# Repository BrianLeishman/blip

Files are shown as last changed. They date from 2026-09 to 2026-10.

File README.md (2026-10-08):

# blip

**Brian’s Little Information Panel.** A little physical home for your GitHub queue:
TinyGo, a color screen, a clickable knob, and a 3D-printed case.

Turn the knob to select something. Click to open it in your computer’s default
browser. Swipe the screen to scroll. One dashboard, no pages or menus.

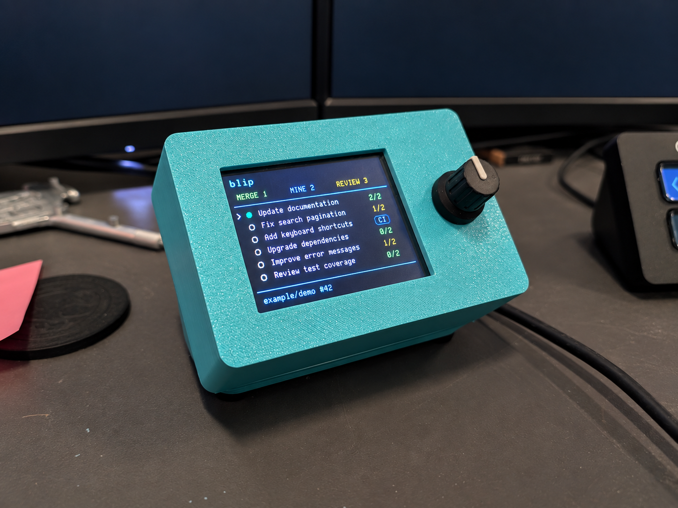
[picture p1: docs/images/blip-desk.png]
A working blip in its teal printed enclosure


*AI privacy edit of the working desk prototype photo: LCD content is fictional
and background monitors are blanked. [Image provenance](docs/images/README.md).*

## What it does

- **Merge:** your PRs that meet the dashboard’s review rules, with failing checks and
  merge conflicts keeping them out of the ready queue. Pending CI is shown with
  a spinner and can still appear here.
- **Mine:** your other PRs, with approval counts, LGTM labels, and CI status.
- **Review:** open, non-draft PRs requesting your review, oldest updated first,
  while they still have fewer than the configured number of approvals. PRs with
  running or failing CI, or merge conflicts, stay hidden until resolved.
- **Urgent:** optional GitHub issue Priority filtering, excluding blocked work.
- **Across repositories:** discover relevant PRs across configured organizations
  and personal accounts; skip archived repositories.
- **Extra authors:** optionally treat Dependabot and configured GitHub accounts
  as yours, hiding their PRs assigned exclusively to somebody else.
- **Comments:** unread human comments on subscribed issues and PRs. Click to open
  the specific comment and clear the alert locally; new comments bring it back.
  Drafts are excluded, queued items appear once, and standalone PR alerts cover
  conversations you've participated in or direct mentions.
- **Deployments:** unresolved failures from configured production workflows.
  A newer successful or cancelled run clears the alert. PR CI failures remain
  in the existing PR status display.

Running checks get a spinner. Long selected titles marquee. Turn past either end
of the list to clear the selection and stop the scrolling title. The footer shows
the item number, repository, and status. Content updates only repaint when the
content changes; animations replace only the affected row as a composed bitmap.

Clicking opens a GitHub page—even when the displayed data is stale. **Blip never
merges a PR, submits a review, or changes an issue.** The Merge section is a personal
queue; GitHub remains authoritative about mergeability and branch protection.

## How it works

```text
GitHub ← authenticated gh CLI ← Go companion on your computer
                                      ↕ USB serial
                              Feather RP2040 + TinyGo
                                ↙              ↘
                           TFT screen       rotary knob
```

The companion fetches GitHub data and opens links. The Feather handles display,
selection, touch scrolling, and button presses. Credentials stay on the computer;
the device receives display data and repository/item IDs, never access tokens.
There is no hosted backend or Wi-Fi setup.

macOS is the tested host. Linux has serial support and an `xdg-open` path, but has
not been hardware-tested. The screen is a **2.4-inch, 320 × 240 color TFT** with
resistive touch.

## Hardware

| Qty | Part |
| --- | --- |
| 1 | [Adafruit Feather RP2040 — #4884](https://www.adafruit.com/product/4884) |
| 1 | [2.4-inch TFT FeatherWing V2 — #3315](https://www.adafruit.com/product/3315) |
| 1 | [STEMMA QT rotary encoder breakout — #4991](https://www.adafruit.com/product/4991) |
| 1 | [Rotary Encoder + Extras — #377](https://www.adafruit.com/product/377), including knob |
| 1 | [100 mm STEMMA QT cable — #4210](https://www.adafruit.com/product/4210) |
| 1 | USB-C **data** cable |
| 1 | Short flexible USB-C extension for routing through the case |
| — | M2.5 board screws, M3 case screws, rubber feet, hookup wire and printed parts |

You will also need soldering tools and a printer or printing service. No battery,
SD card, or breadboard is required. See the [assembly guide](enclosure/v2/ASSEMBLY.md)
for screw lengths, wiring, and the current fit limitations before buying or printing.

For a first bench test, the Feather can plug directly into the FeatherWing’s two
header sockets; match the pin labels. Solder the rotary encoder into its breakout
and connect the breakout’s QT cable to the **Feather’s QT port**.

The compact case relocates the Feather using eight wires: **3.3V, GND, SCK, MOSI,
D9, D10, SDA, SCL**. Important: use the FeatherWing’s **3.3V socket, second from
RST**; the next socket is AREF. The [wiring guide](enclosure/v2/ASSEMBLY.md#eight-wire-connection)
explains the orientation and optional connections.

## Get it running

Requires Go matching [go.mod](go.mod) (currently 1.26.6+), TinyGo 0.42+, and the
GitHub CLI. Python 3 is only needed for the optional macOS service installer and
CAD utilities; OpenSCAD is needed to regenerate the printed parts.

```sh
git clone https://github.com/BrianLeishman/blip.git
cd blip
gh auth login
make all
```

For the first flash, hold **BOOTSEL**, tap **RESET**, then release BOOTSEL. Copy
`build/blip.uf2` to the `RPI-RP2` drive. Before the companion connects, the hardware
test screen shows knob position and click counters.

```sh
cp blip.example.json blip.local.json
# Edit blip.local.json: replace the example owners with yours.
make run
```

The companion detects the connected Adafruit serial device and reconnects after
unplugging it. Use `./build/blip -port /dev/cu.usbmodem…` if detection is ambiguous.
`make probe` prints hardware events; `./build/blip -once` prints a GitHub snapshot
without connecting to the device. The latter can include private repository data.

To keep the companion running at login on macOS:

```sh
python3 scripts/macos-service.py
# To remove it later:
python3 scripts/macos-service.py --uninstall
```

Before probing or flashing, stop the service so only one process owns the port:

```sh
launchctl bootout gui/$(id -u)/com.brianleishman.blip
make flash
python3 scripts/macos-service.py
```

See [configuration and dashboard behavior](docs/dashboard.md) for review rules,
urgent issue queries, polling limits, stale data, and troubleshooting.

## Printed enclosure

OpenSCAD source and printable STLs are included. The case is meant to be tinkered
with: a tilted screen, knob on the right, a hollow base, and a rear USB cable plate.

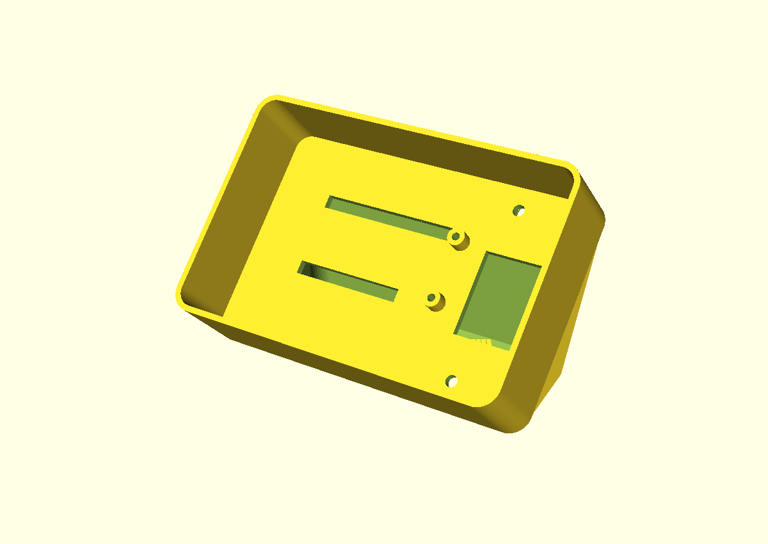
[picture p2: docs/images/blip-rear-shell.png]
Latest rear-shell CAD render, showing Feather mounts and header clearance slots


*CAD render of the latest revision. This is newer than the case in the photo and
has not yet been physically printed and verified.*

The photographed build works, but the rotary fit is tight and wiring space needs
improvement. The latest CAD moves the sidewalls onto the rear shell, outside the
fit-tested face area, and adds clearance slots for the Feather’s pins. It still
uses **two Feather posts**; four slightly taller posts are planned, not implemented.

- [Assembly and print instructions](enclosure/v2/ASSEMBLY.md)
- [Parametric OpenSCAD source](enclosure/v2/assembly.scad)
- [Front plate STL](enclosure/stl/v2-front-m25.stl)
- [Rear shell/base STL](enclosure/stl/v2-stand.stl)
- [USB plate STL](enclosure/stl/v2-usb-plate.stl)
- [All three parts, arranged for printing](enclosure/stl/v2-print-layout.stl)

```sh
make enclosure-v2
```

The combined STL is a layout of **three separate parts**, not an assembled solid.
Mesh and modeled-clearance checks help catch CAD mistakes, but do not validate
real wire bends, printer tolerances, or physical fit. Earlier enclosure experiments
remain in [enclosure/](enclosure/README.md).

## Development and privacy

```sh
make test       # Go tests and vet
make firmware   # TinyGo build, without flashing
```

`firmware/` drives the hardware, `dashboard/` shares the wire model and list behavior,
and `cmd/blip/` plus `internal/github/` implement the companion.

Personal configuration, build output, logs, and environment files are ignored.
Do not commit live snapshots or unredacted photos: titles, repository names, and
computer screens can reveal private work even without a token. See
[security and privacy notes](SECURITY.md) before sharing diagnostics.

## License

MIT. Dependencies keep their own licenses. Adafruit’s hardware designs are
separately licensed and linked as dimensional references; their PCB files are not
vendored here.

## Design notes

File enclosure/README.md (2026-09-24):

# OpenSCAD enclosure

`blip.scad` is the editable source. `stl/front.stl` and `stl/back.stl` are generated
from it. The default view is an exploded assembly. Select `part="fit"` to export
a shallow bezel/mounting test before printing the complete case. The fit test
uses 1.7 mm board pilot holes for M2 screws and 2.6 mm case pilot holes for
M3 screws to form threads directly in printed plastic. No inserts or captive nuts are needed. Test screw fit gently
before mounting the electronics; adjust `board_screw_pilot` or `case_screw_pilot` if your print is too tight
or too loose, especially with nylon screws. Do not force a screw that binds.

**Prototype: not physically fit-tested.** PCB outline and mounting-hole centers
come from Adafruit's V2 Eagle file. Screen stack height, viewing-window alignment,
encoder bushing fit, cable opening, and screw fit still need checking
against the assembled hardware. Do not treat these exports as a proven fit.

## Geometry and hardware

- 115 x 76 x 32 mm case; 2.4 mm walls and a 2 mm face.
- Screen PCB: 64.770 x 52.578 mm in landscape, holes inset 2.540 mm.
- Screen mounting pattern is mirrored horizontally about the unchanged window
  center, swapping the close and far pairs. This moves the PCB origin from
  x=8 to x=11.63 mm while retaining the mounting-hole spacing.
- Four screen posts with M2 pilot holes. LCD-facing sides are trimmed to
  2.0 mm from each screw center; the outer sides retain the original radius.
- Four case posts with M3 pilot holes; rear lid has 3.3 mm clearance holes.
- Encoder mounts through the face with its included washer/nut. Two 3 mm
  tall rails locate its metal body against rotation. Their 13.8 mm spacing
  includes 0.3 mm clearance per side around the nominal 13.2 mm body.
  Rails are rotated 45 degrees to match the encoder-to-breakout orientation;
  verify fit before tightening. Adjust `encoder_gap`/`encoder_angle` if needed.
- Broad top-edge USB service opening leaves clearance for the cable; refine after fitting.
- Flat rear lid with vents; rubber feet attach to its outside.

The revised screen posts are 2.54 mm shorter, leaving 2.96 mm of blind-hole
depth. Use M2 x 4 mm screws with a 1.6 mm PCB (2.4 mm engagement), or check
your actual stack so screw protrusion stays below 2.96 mm. The earlier
6 mm screen screws are too long without suitable spacers.
The rear lid is 2.4 mm thick; a 6 mm screw leaves 3.6 mm engagement in the shell.
Do not tighten against the LCD glass.
The knob must retain enough axial clearance to click without rubbing the face.
The current shell is flat; an angled desk stand can be added after hardware fit.

Print front face-down (the SCAD export already places that face on Z=0), and back
flat. Suggested starting settings: 0.2 mm layers and three perimeters. The USB
opening involves a bridge; use supports locally if required
by your printer/material. Printer and filament are user-supplied.

```sh
make enclosure
openscad -o build/fit.stl -D 'part="fit"' enclosure/blip.scad
```

Physical fit feedback: with the screen readable, USB exits below it. The
current full shell's top service opening is therefore not validated and must
be rerouted before a full-case print. The shallow fit test does not depend on
USB opening position.

Use `stl/bezel-fit-mirrored-short.stl` for the revised combined fit test.
Previous fit exports are superseded. For a smaller encoder-only trial, export
`part="encoder-fit"`; it checks body indexing and knob click clearance.

Dimensional sources:
- https://github.com/adafruit/Adafruit-2.4-TFT-FeatherWing-PCB
  (`Adafruit 2.4in TFT FeatherWing V2.brd`)
- https://learn.adafruit.com/adafruit-2-4-tft-touch-screen-featherwing/downloads
- https://www.adafruit.com/product/377

The vendor CAD was read for dimensions and is not included in this repository.

Encoder dimensions: [Adafruit encoder PCB](https://github.com/adafruit/Adafruit-I2C-QT-Rotary-Encoder-PCB),
`PEC11+SWITCH` package (13.2 mm body outline, center-mounted at MR135).

## Compact enclosure with 45-degree stand

`slim.scad` is the current enclosure. `blip.scad` retains the larger fitting
reference. The face is 104 x 61 mm, with the corrected screen offset and
4.96 mm PCB mounting height. Shell plus rear cover depth is 32 mm. The stand
holds the face at 45 degrees; assembled desk footprint is approximately
104 x 68 mm, about 70 mm high, excluding rubber feet.

Build all current parts with `make enclosure-slim`:

- `stl/slim-front-m25.stl`: front shell, relieved screen posts, encoder rails.
- `stl/slim-stand.stl`: hollow stand and rear cover, printed as one part.
- `stl/slim-usb-plate.stl`: replaceable rear cable plate.
- `stl/slim-face-fit-m25.stl`: optional shallow fit print using the same mounts.

Hardware:

- Four M2.5 x 4 mm pan/button-head screws for the screen PCB. Vendor CAD
  specifies 2.5 mm drilled mounting holes; check free passage on the actual
  plated board. Printed pilot holes are 2.2 mm. The nominal 1.6 mm PCB leaves
  2.4 mm screw engagement in 2.96 mm-deep blind holes. Do not use 8 mm screws.
- Four M3 x 8 mm screws fasten the stand/rear cover to the shell (2.4 mm cover,
  5.6 mm engagement). Four 7.5 mm access bores in the stand admit the heads
  and a slim driver. Two are reached from the back, two from underneath.
- Two M3 x 6 mm screws fasten the rear cable plate. A small zip tie secures
  the extension body using the adjacent slots; do not clamp bare ribbon wire.
- Encoder's supplied nut and washer, plus the existing rubber feet.
- No inserts or captive nuts required.

Assembly: fit the screen using the short screws, install the encoder between
its indexing rails and secure its nut, connect QT and USB, route the USB
extension through the 24 x 12 mm rear-cover transfer opening into the hollow
stand, and attach the stand using the four M3 screws. The cover has an inset
locating skirt. Secure the extension at the rear plate, attach the plate,
and place rubber feet on the four solid underside corner areas. The large
underside opening provides access to wiring and the lower cover screws.

USB routing is designed for a short flexible **data-capable** USB-C male-to-
female extension, preferably with a low-profile right-angle male connector.
The current rear plate has a generic 18 x 10 mm pass-through and tie slots;
it is not a precision panel mount for an identified cable. Adjust `usb_slot_w`
and `usb_slot_h`, or replace just this plate, once the extension is selected.
The lower shell service opening accommodates the plug; exact connector/body
clearance and cable bend radius remain physical-fit checks. The QT board gap
is nominally 4.13 mm, so check the QT connector/cable clearance too.

Print the front face down, the stand base down, and the cable plate flat,
as exported. Start with 0.2 mm layers and 3-4 perimeters. Inspect the slicer:
local supports may be useful under the shell USB opening and the stand's
rear cable opening; avoid filling the entire hollow stand with supports.
The sloped roof starts on a supporting front lip. All parts remain prototypes
until physically assembled; rendering alone does not validate hardware fit.

## Tapered cable-pocket revision (September 23)

`tapered.scad` is a separate fit prototype; `slim.scad` remains unchanged.
The user confirmed USB currently exits the top with the knob on the right.
This revision rotates the PCB mount pattern 180 degrees about the unchanged
screen opening so USB exits below the display. The front shell has been physically installed and the user reports it clears,
with little spare room. Firmware now uses Rotation270 with the matching
touchscreen mapping for this orientation. Base fit is still pending.

The front stays 104 x 61 mm with the same screen opening and knob placement.
Behind it, the case flares to 116 x 76.24 mm: 6 mm per side and an additional
15.24 mm (0.600 inch) below the original lower inner wall. Side relief reaches
full width at the 4.96 mm PCB plane; lower relief reaches full size 12 mm behind
the front face. These are provisional cable envelopes, not measured plug models.
The lower pocket routes through a 40 x 18.24 mm opening into the hollow stand.
The stand matches the enlarged rear cover and still holds the face at 45 degrees.
The underside is raised to keep the enlarged shell above the desk.

Build with `make enclosure-tapered`:

- `stl/tapered-front-m25.stl`
- `stl/tapered-stand.stl`
- `stl/tapered-face-fit-m25.stl` (optional shallow mounting check)

Reuse `stl/slim-usb-plate.stl` and the M2.5 x 4 mm / M3 hardware described above.
The left PCB bosses are clipped at the front edge after rotation; no inserts.
The rear connector plate remains a generic opening, pending actual female
connector measurements. Do not assume it is a precise clamp for the new cable.

Print front face-down with supports as needed under the outward flare (the
side flare is steep); stand base-down. Inspect support access in the slicer.
Verify USB connector depth, bend clearance, QT routing, and the rotated screen
alignment before a final print. The shallow coupon checks mounting, not cables.

## V2 packing study

The [V2 component study](v2/README.md) uses vendor PCB outlines and explicit
connector-clearance estimates to compare stacked and relocated Feather layouts.
Open `v2/packing.scad` to inspect; run `make enclosure-v2-check` for envelope and
collision reports. This is separate from the assembled V1 tapered enclosure.

## Compact V2 full assembly

See [V2 assembly instructions](v2/ASSEMBLY.md) for the 97.57 × 65 × 28 mm case,
upside-down relocated Feather and required low-profile wiring. Run
`make enclosure-v2`; `stl/v2-print-layout.stl` contains all three printable parts.

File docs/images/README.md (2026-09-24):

# README image provenance

`blip-desk.png` is an AI privacy edit of the author's photograph of the working
printed prototype. Background monitor content was removed and LCD content
replaced with fictional demo items. It is not an exact screenshot of the firmware.
The original work photograph is intentionally not included in the repository.
The edit used the built-in imagegen tool. PNG metadata was removed without
changing the rendered pixels.

`blip-rear-shell.png` is an OpenSCAD render of `enclosure/v2/assembly.scad` with
`part="stand"`, showing the newer rear-shell walls and header-clearance slots.
That revision has not been physically printed and verified.

## Photo edit prompt

Use case: precise-object-edit. Edit this real project photograph for a public GitHub README. Preserve the real teal 3D-printed enclosure, its shape, textured filament, black knob, desk, perspective, and lighting exactly. Privacy edits only: replace ALL content on ALL background computer monitors with plain dark blank screens, no text or windows. Replace ALL content on the small device LCD with a similar tiny pixel-font dashboard containing only fictional generic demo text: header 'blip', tabs 'MERGE 1  MINE 2  REVIEW 3'; rows 'Update documentation', 'Fix search pagination', 'Add keyboard shortcuts', 'Upgrade dependencies', 'Improve error messages', 'Review test coverage'; generic badges '2/2', '1/2', 'CI', '0/2'; footer 'example/demo #42'. Absolutely remove every original PR title, number, repository name, customer name and all original LCD footer content. Do not change hardware or invent new features. Keep realistic photographed LCD perspective and pixelated appearance. Crop excess empty desk for a landscape hero image while keeping the complete device and base. No added branding, annotations, watermarks, or other text.

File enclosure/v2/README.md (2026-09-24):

# V2 enclosure and component packing study

**Current full-case prototype:** [assembly and printing instructions](ASSEMBLY.md).
The notes below retain the earlier packing-study comparisons. The full case now
uses the successfully tested eight-wire relocation and an upside-down Feather.

`packing.scad` models the existing boards and provisional connector clearances to
compare layouts before designing another enclosure. **This is not a printable
case or a guarantee of physical fit.** V1 remains in `../tapered.scad`.

Open `packing.scad` in OpenSCAD. Set `layout` to `stacked`, `remote-flat`, or
`remote-edge`; `qt_source` chooses `feather` (default) or `screen`; `view` supports `assembly`, `exploded`, `collision`, and `envelope`.
Green is the screen PCB, blue the Feather, purple the encoder PCB, and amber the
reserved connector/cable space. Red indicates intersections included in the
collision check. Axes: x right, y down the display, z behind its face; the knob
projects into negative z. This is a component layout, not the tilted desktop stand.

## Published geometry

| Part | PCB outline from vendor CAD | Other published dimensions |
|---|---|---|
| [TFT FeatherWing V2 #3315](https://www.adafruit.com/product/3315) | 64.770 × 52.578 mm landscape | Product overall height 9.5 mm; LCD footprint outline 60.15 × 42.6 mm |
| [Feather RP2040 #4884](https://www.adafruit.com/product/4884) | 50.800 × 22.860 mm | Product overall height 7.5 mm, not assembled header-stack height |
| [Encoder breakout #4991](https://www.adafruit.com/product/4991) | 25.400 × 25.400 mm | Product height 4.6 mm without the separately soldered encoder |
| [Encoder + knob #377](https://www.adafruit.com/product/377) | Encoder body footprint 13.2 × 13.2 mm | Supplied knob base diameter 16 mm, height 14.5 mm |

All three PCB mounting-hole drills are 2.5 mm in the CAD. Mounting holes and
connector centers are preserved in `vendor-dimensions.json`; board outlines and
holes are exported to `dimensions.scad`. Dimensions are in millimeters.

Sources: Adafruit's [TFT CAD](https://github.com/adafruit/Adafruit-2.4-TFT-FeatherWing-PCB),
[Feather CAD](https://github.com/adafruit/Adafruit-Feather-RP2040-PCB), and
[encoder breakout CAD](https://github.com/adafruit/Adafruit-I2C-QT-Rotary-Encoder-PCB),
plus the linked [knob drawing](https://cdn-shop.adafruit.com/datasheets/EPD-200732.pdf)
and [PEC11 drawing](https://cdn-shop.adafruit.com/datasheets/pec11.pdf).
These are simplified envelope models, not detailed manufacturer STEP models.

## Assumptions that still need checking

- PCB thickness 1.6 mm; LCD depth 3.4 mm; rear socket height 4.5 mm. These split
  the screen's published 9.5 mm total but do not establish the real Z positions.
- Feather components occupy a conservative full-board 5.9 mm box above its PCB.
  Soldered male headers, pin tails, adapter sockets and ribbon termination heights
  are not individually modeled. Thus the stacked Z placement is provisional too.
- Encoder assembly depth is 12 mm from the modeled body front to the PCB rear.
  The knob's external dimensions are known; bushing/shaft engagement and face
  thickness must be resolved when making the case.
- QT plugs plus wire bends reserve 8 mm outside a board edge. The screen plug
  deliberately has its own space above the PCB edge. Actual cable paths are not
  modeled; the two plugs must still be joined without pinching the cable.
- USB male plug reserves 15.24 mm beyond the Feather, based on the V1 clearance
  report. Its box does not reproduce the specific right-angle plug shape.
- The panel USB socket is a **16 × 12 × 10 mm placeholder**, not a selected product.
  It excludes mounting flanges and screws; select a real data-capable panel cable
  and replace this envelope before creating its cutout.
- The remote Feather has 3 mm nominal wire space behind the encoder envelope.
  A real header/ribbon adapter may need appreciably more room.

## Layouts and verification

Run `make enclosure-v2-check` to export envelopes and intersections into
`build/v2/` and write `results.json`. Only OpenSCAD and Python's standard library
are required; generated dimensions are already included in the repository.

- **Stacked:** conventional Feather behind the FeatherWing, USB extending past
  the lower board edge.
- **Remote flat:** Feather stays parallel to the LCD but is relocated and rotated
  so USB points toward the encoder bay. This tests rerouting, not a base-mounted
  Feather parallel to the desk.
- **Remote edge:** Feather turns 90 degrees behind the screen. This trades depth
  for placement freedom and is not automatically slimmer.
- **Remote close:** same flat position with `board_gap=-2`, allowing the encoder
  PCB to overlap the display PCB's XY outline by 2 mm at a different depth. This
  tests whether the hidden encoder body, rather than its PCB outline, limits spacing.

Initial results with the encoder cable on the **screen** (superseded by Feather routing, 2026-09-24):

| Candidate | Modeled envelope, W × H × D (mm) | Modeled intersection |
|---|---|---|
| Stacked | 92.17 × 75.82 × 30.40 | Yes: reserved screen QT bend space overlaps Feather |
| Remote flat | 92.17 × 64.58 × 30.40 | None |
| Remote edge | 101.41 × 64.58 × 41.26 | None |
| Remote close | 88.17 × 64.58 × 30.40 | None |

The close variant moves the knob 4 mm inward relative to the flat baseline. Its
estimated encoder-body-to-screen-PCB edge gap is only about 1.37 mm; add mounting
and indexing geometry before relying on that spacing. The generic panel socket
sets the 30.4 mm depth in the flat variants, so choosing the real socket matters.
The stacked intersection involves a provisional **bend clearance**, not proof
that the actual assembled boards intersect.

Envelope sizes exclude the external knob, case walls, bezel, stand, fasteners,
wire harness and strain relief. They include the provisional cable/socket boxes.
Do not compare them directly with V1's complete case dimensions.

Collision checks compare the display/encoder groups against the Feather and USB
clearance, the display against the encoder, and the panel socket against those
parts. They also include the modeled QT clearance boxes. An empty intersection
means **no collision among these modeled envelopes**, not a validated assembly.
Intended internal contact within each component group is excluded. Actual cable
bends, mounting posts, tool access and electrical behavior remain untested.

Updated results with the encoder connected to the **Feather**:

| Candidate | Modeled envelope, W × H × D (mm) | Modeled intersection |
|---|---|---|
| stacked-close | 88.17 × 74.04 × 30.40 | None |
| stacked | 92.17 × 74.04 × 30.40 | None |
| remote-flat | 93.19 × 56.58 × 30.40 | None |
| remote-edge | 101.41 × 56.58 × 41.26 | None |
| remote-close | 89.19 × 56.58 × 30.40 | None |

The stacked model still reserves space beyond the Feather for its QT plug/bend;
that space is behind the display plane, so the final shell can accommodate it
without necessarily increasing the front bezel. Physical routing must confirm this.

## Direction for the next case

First try the existing **stacked Feather**, with the encoder cable connected to the
Feather's own STEMMA QT port. Both boards' CAD files connect QT pins 3/4 directly
to SDA/SCL on their Feather headers; `firmware/main.go` already initializes
`machine.I2C1` with `machine.SDA_PIN` and `machine.SCL_PIN`. No firmware change is
needed. Power off before moving the cable. Touch remains connected over the headers.
Adafruit confirms the shared bus in its [Feather pinout guide](https://learn.adafruit.com/adafruit-feather-rp2040-pico/pinouts).

The study now reserves QT plug/bend space at the Feather port instead of at the
screen port. This removes the plugged cable from the LCD edge; it does not remove
the bare screen socket or the need for cable space elsewhere. Test the real bend
behind the Feather before fixing case height. The riser remains an optional second
step if USB/depth still calls for it. The flat remote arrangement remains a candidate,
while standing the Feather on edge costs depth in the current study.

The proposed "riser" is a short Feather-specific harness/adapter, **not PCIe**.
The two rows have 16 and 12 positions at 2.54 mm pitch. A one-to-one connection
preserves the existing wiring, but its orientation and pin mapping must be checked
against both boards before power. No ready-made compatible riser has been verified.
Ordinary jumper/socket housings may erase the space savings. A short custom ribbon
adapter is a candidate; SPI signal quality must be checked on hardware, and the
current display clock may need reducing. CAD cannot establish that.

Next inputs: actual panel-mount USB cable geometry, riser termination dimensions,
and eventually assembled stack/QT-bend measurements. Then add the face, indexing
features, mounting posts and sloped base around the chosen component arrangement.

## Regenerating the dimension extraction

`scripts/v2-dimensions.py` expects these vendor files (not needed for normal renders):

- `build/tft-cad/Adafruit 2.4in TFT FeatherWing V2.brd`
- `build/feather-cad/Adafruit Feather RP2040.brd`
- `build/encoder-cad/Adafruit I2C QT Rotary Encoder.brd`

Download from the linked vendor repositories and run `python3 scripts/v2-dimensions.py`.
The extraction records XY facts only; it does not infer component heights.

## First print: closer-knob front fit

[`front-fit.scad`](front-fit.scad) produces
[`../stl/v2-front-fit-m25.stl`](../stl/v2-front-fit-m25.stl). This is a shallow,
open-backed mounting coupon, not a replacement case. It preserves V1's corrected
screen-window offset, 2.2 mm M2.5 pilot holes and
encoder indexing rails. Screen supports are now **5.468 mm** high: the original
4.96 mm plus 0.020 inch (0.508 mm), following physical fit feedback that the
shorter supports compressed the LCD. The screen orientation stays the same as the assembled
V1; the knob remains on the right from the readable side.

- Overall 93.57 × 61 × 5.468 mm; face is 2 mm thick.
- Knob center is 9.76 mm closer to the screen PCB than in `tapered.scad`.
- Encoder PCB overlaps the screen PCB outline by 2 mm at different heights.
- Existing M2.5 × 4 mm screen screws and the encoder's nut/washer fit the intended
  mounting scheme. No threaded inserts. The pilot bottoms are 3.468 mm below the
  support surface; do not substitute long screws that could pierce the face.
- Print broad flat face down, posts/rails up, 0.2 mm layers and 3 walls. No supports
  are intended. Use the same material as the successful V1.
- With USB unplugged, fit the screen and encoder without forcing either. Check
  the four supports seat, LCD opening aligns, the encoder body fits the rails,
  board backs/solder joints do not touch, and knob turns/presses freely. Move the
  QT cable to the Feather and check its bend with the Feather still stacked.
- This coupon has no rear walls or case fasteners. It cannot validate USB routing,
  a future lid/stand, or a Feather riser. All electronic assembly Z envelopes remain
  estimates; the physical coupon is intended to resolve the closer-knob fit.

Regenerate with `make enclosure-v2-fit`. `part="preview"` shows component proxies;
`part="clearance"` intersects the coupon with rigid board/body proxies and a 6 mm
screen-screw access envelope. On the first export the clearance intersection was
empty, and the STL was one connected watertight mesh with its minimum Z at zero.

## Panel USB candidates (not selected)

[DataPro 1678](https://www.datapro.net/products/usb-c-panel-mount-extension-cable.html)
has a 6-inch option, USB 2.0 compatibility, included 4-40 mounting screws and a
published drawing/STEP model. Its flange, round cable and plug need checking against
the compact layout; the current generic panel socket is not a model of this cable.
[Adafruit 6069](https://www.adafruit.com/product/6069) is another round panel-mount
option. Neither has been selected or purchased. A printed capture bracket for the
user's existing flexible extension is also worth evaluating before adding a cable.

The taller-post revision is also exported as `../stl/v2-front-fit-m25-taller-posts.stl`
to distinguish it from the earlier 4.96 mm-support print.

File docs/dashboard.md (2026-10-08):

# Dashboard configuration and behavior

```sh
cp blip.example.json blip.local.json
# Edit your owners, urgent issue query, and approval threshold.
make run
```

`blip.local.json` is ignored by Git. GitHub credentials stay in your existing `gh`
login, on the computer. The device receives titles and repository/item IDs, never tokens.

Configure `owners` with GitHub organization/user names to include all their
repositories accessible to your `gh` login. New repositories are discovered on
each refresh from your open non-draft PRs and review requests. You can also add
explicit `repositories` (`owner/repo`); overlapping repositories are deduplicated.
Archived repositories are excluded from PRs and urgent issues.
Set `include_dependabot` to `true` to treat `dependabot[bot]` PRs as your own,
using the same Mine/Merge, approval, conflict, and CI rules. PRs that also request
your review appear once in Mine/Merge. Dependabot PRs assigned solely to other
people are hidden (including from Review); unassigned PRs and PRs assigned to
you remain visible.
Set `additional_authors` to a list such as `["your-other-account"]` to treat
those accounts' PRs the same way, including the assignment filter above. This
works independently of `include_dependabot`, within your configured owners and
repositories. Repositories containing only these authors' PRs are discovered too.
Overlapping author and review results appear once; your own account's PRs remain
visible regardless of assignee.
Urgent issues are disabled in the example configuration. They use their own
`urgent_query` scope; use `(org:YOUR_ORG OR user:YOUR_NAME)` for both owners.

Two optional alert types appear first in the same continuous list: failed
deployments, then comments. They do not add pages or change the knob controls.

```json
{
  "comments_since": "2026-10-05T00:00:00Z",
  "deployments": [
    {"repository": "your-org/service", "workflow": "deploy.yml", "branch": "main"}
  ]
}
```

`comments_since` is a fixed initial cutoff, not a moving daily window. Set an
RFC3339 timestamp to enable comments; leave it empty to disable them. Local midnight
may require a UTC offset, for example `2026-10-05T00:00:00-04:00`.
`deployments` is an explicit allowlist of workflow filenames or IDs and production
branches within your configured repository/owner scope. No guessing from workflow
names, and no blanket list of failed Actions runs. Archived repositories are skipped.

- **C / Comments:** one row per unread notification thread, opening its latest
  human issue comment, PR conversation comment, inline review comment, or review
  containing text. Comments must be newer than both the initial cutoff and the
  thread's GitHub read timestamp. Bots, your own comments, empty review votes,
  CI notifications, and state changes without a new human comment are excluded.
  Draft PRs do not produce comment alerts. Standalone PR comment alerts require
  earlier participation (you authored, commented on, or reviewed the PR), or an
  unread human comment directly mentioning your account. An existing PR/issue row
  takes precedence over its comment row, so a queued item appears only once.
  Draft state is checked on each refresh even when comment contents are cached.
  Conflicted PRs that are not treated as yours are also excluded from comment alerts.
  Threads can be mentioned, subscribed, authored, assigned, or otherwise present
  in your unread inbox; the notification reason alone does not prove a new comment.
  The title identifies the commenter and issue/PR. `@YOU` identifies a thread
  with GitHub's mention reason; `NEW` identifies other threads. This does not
  prove the latest comment itself mentions you. Unchanged threads reuse cached
  comment data until GitHub reports new activity or a different read timestamp.
  Discussions are not currently included.
  A successful browser-open command clears that comment alert immediately on blip.
  A later human comment gets a new ID and returns. Acknowledgments persist beside
  your config in an ignored `*.alerts.local.json` file, independently of GitHub's
  inbox; clicking does not mark GitHub notifications read or unsubscribe you.
- **D / Deployments:** the latest meaningful completed result per configured
  workflow and branch. Failure, timeout, startup failure, and action-required
  results show a red `FAIL`; a newer success or cancellation clears the alert.
  Cancellation is not treated as successful deployment, and never creates an alert.
  A retry in progress keeps the prior failure visible. Skipped/neutral runs do not
  hide a prior failure or create an alert. Clicking opens the failed Actions run.
  Only push, manual dispatch, repository dispatch, release,
  and schedule events are eligible. PR events and runs linked to PRs are excluded,
  even if they use the production branch. The latest unfiltered workflow history
  is fetched and branch/event/outcome rules are applied locally, avoiding old
  results from filtered Actions searches. Up to 1,000 runs are inspected
  per workflow to find the latest eligible completed result; reaching that limit reports a
  refresh error. This observes workflow outcomes, not actual service health.
  Deployment results are cached for two minutes between polling cycles to limit
  Actions API traffic; browser opening and comment dismissal remain immediate.

The companion uses GitHub's [notification API](https://docs.github.com/en/rest/activity/notifications)
and [workflow-run API](https://docs.github.com/en/rest/actions/workflow-runs).
The CLI login needs access to notifications and Actions in the relevant repositories.

- **M / Merge:** your non-draft PRs with enough effective approvals, GitHub's
  approved review decision, or **no outstanding review requests**. This is your
  personal merge queue, not a claim that all branch protections pass.
  A changes-requested decision, failing check, or merge conflict keeps the PR in Mine.
  Conflicts show a red `CONFLICT` badge; approvals and CI remain in the footer.
- **O / Mine:** your other non-draft PRs, awaiting reviewers, changes, or CI fixes.
  Both own-PR groups show `n/n` approvals, `L+`/`L-` for the actual LGTM label,
  and CI status: `+` successful, `~` pending, `?` no checks. Failures take
  priority in the row badge (`n/n FAIL`), with LGTM still in the footer.
  PRs with queued/running CI show a spinner, including those with a failed
  job and other jobs still running. Animated rows are composed in a reusable RGB565
  buffer and sent as one bounded bitmap, with separate title, spinner, and badge
  clips. There is no visible blanking pass between frames; unchanged row images
  and unchanged refreshes do not repaint the screen. CI animation stops when data is stale.
  Highlight an item to see its number, abbreviated repository, and compact status
  together on one footer line. Long repository names shorten before status; the
  list shows ten rows at a time. Long selected titles scroll after a short
  reading pause, replacing only that row's bitmap. Turn past either end of the list
  to clear the highlight and stop title scrolling; turn back to select again.
  Refreshes preserve that unselected state, and clicking it opens nothing. A successful
  LGTM-label workflow does not itself count as the LGTM label.
- **R / Review:** `is:open -is:draft review-requested:@me`, sorted by **least
  recently updated**, with fewer than the configured number of approvals.
  PRs with merge conflicts are hidden until the conflict is resolved. Your own,
  eligible Dependabot, and additional-author PRs keep their conflict status visible
  in Mine.
  PRs with queued/running checks or failed checks (including cancelled, timed-out,
  or action-required runs) are hidden until those checks clear. PRs with no checks
  remain eligible, as do successful, skipped, or neutral checks. This filter applies
  only to Review; your own, Dependabot, and additional-author PRs keep their CI status
  visible in Mine/Merge.
  All review pages are fetched; duplicate approvals from one person count once.
  Bots and the author are excluded. Comments do not revoke an approval; a later
  changes-requested or dismissed review does. GitHub remains authoritative about
  reviewer eligibility and branch protection.
- **! / Urgent:** open issues whose native **Priority** field is **Urgent**.
  Issues with a native or project Status containing the word **Blocked**
  (including department-prefixed statuses), or **Dev: QA**, are excluded.
  `urgent_query` uses advanced issue search, for example
  `org:YOUR_ORG is:issue is:open field.priority:Urgent sort:updated-asc`.
  To show only issues assigned to you or nobody, add
  `(assignee:@me OR no:assignee)` to the query. Assignment filtering comes from
  this query, not a hard-coded organization or account.
  This works across repositories independently of project membership or labels.
  Returned native Priority values are verified. Leave the query empty to disable
  urgent issues; the urgent count hides when zero.

Clicking an item only opens its GitHub page. It never merges, approves, or edits.

Repositories are fetched with up to four concurrent workers, preserving stable
row ordering. A new refresh starts 30 seconds after the previous fetch completes. Swipe up/down with light pressure on the resistive touchscreen to scroll the
list; touch does not open links. The knob still selects and opens items.
Turning the knob scrolls the single list when
needed. Refreshes preserve the highlighted item by ID. The display marks stale
content STALE DATA; clicking a displayed item still opens its GitHub URL
immediately, even before the first refresh after a companion restart. Links are
constructed from validated `owner/repo/pull/number` or `owner/repo/issues/number`
IDs on the fixed `github.com` host, without checking snapshot age or revision.
Comment IDs add validated numeric GitHub comment anchors; deployment IDs use
`owner/repo/actions/runs/number`. All three kinds open immediately with stale data.
A maximum of 60 rows is sent to the device after locally acknowledged comments
are removed, with truncation shown in the footer.
Large payloads are shortened further to fit the device's 16 KiB input buffer,
with `USB limit` shown in the footer. Higher-priority rows are retained first.
GitHub CLI queries are capped at 1,000 candidates per category and repository.
Owner discovery rejects searches reaching 1,000 candidates rather than silently
omitting repositories. Newly opened PRs may wait for GitHub search indexing.
The small bitmap font currently uses ASCII, replacing unsupported characters.

```sh
./build/blip -once                    # inspect current GitHub data
./build/blip -port /dev/cu.usbmodem…  # choose a port if auto-detection is ambiguous
```

The companion reconnects after USB disconnects. To run it automatically at login
(requires Python 3 for this installer only):

```sh
python3 scripts/macos-service.py
# Remove the background service:
python3 scripts/macos-service.py --uninstall
```

Logs live in `~/Library/Logs/blip/companion.log`. Stop the service before using
`make probe` or flashing, so only one process owns the serial port:
`launchctl bootout gui/$(id -u)/com.brianleishman.blip`.
Re-run the installer afterward to start it again.

macOS is the primary host; Linux has a basic `xdg-open` path but has not been hardware-tested.

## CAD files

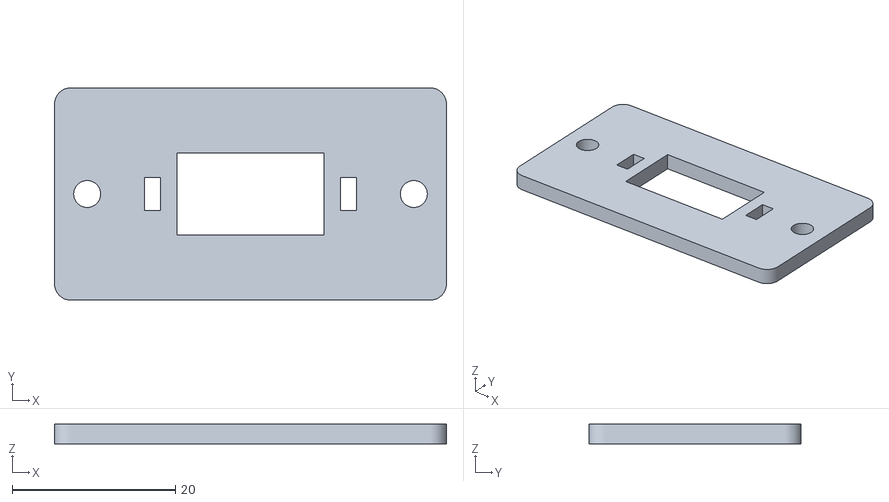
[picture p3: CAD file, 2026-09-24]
enclosure/stl/slim-usb-plate.stl
48.0 x 26.0 x 2.40

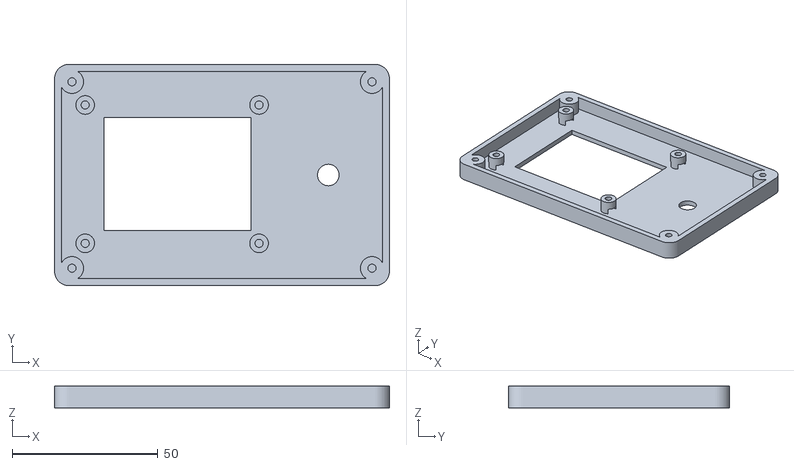
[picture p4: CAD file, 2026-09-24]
enclosure/stl/bezel-fit.stl
115.0 x 76.0 x 7.50

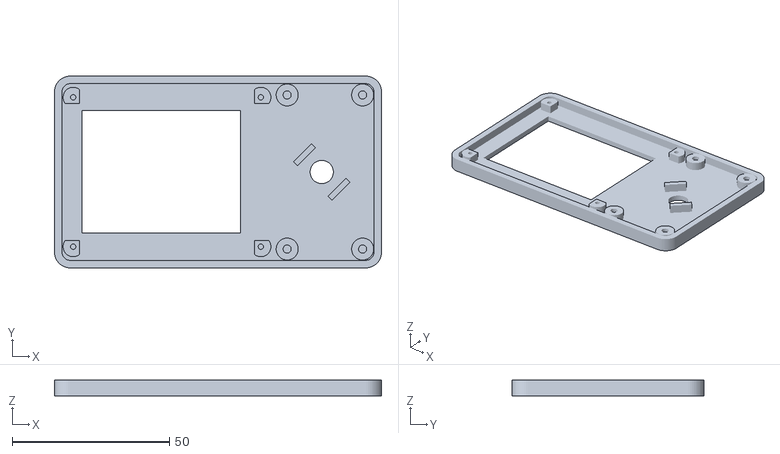
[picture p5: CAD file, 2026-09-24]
enclosure/stl/slim-face-fit.stl
104.0 x 61.0 x 5.00

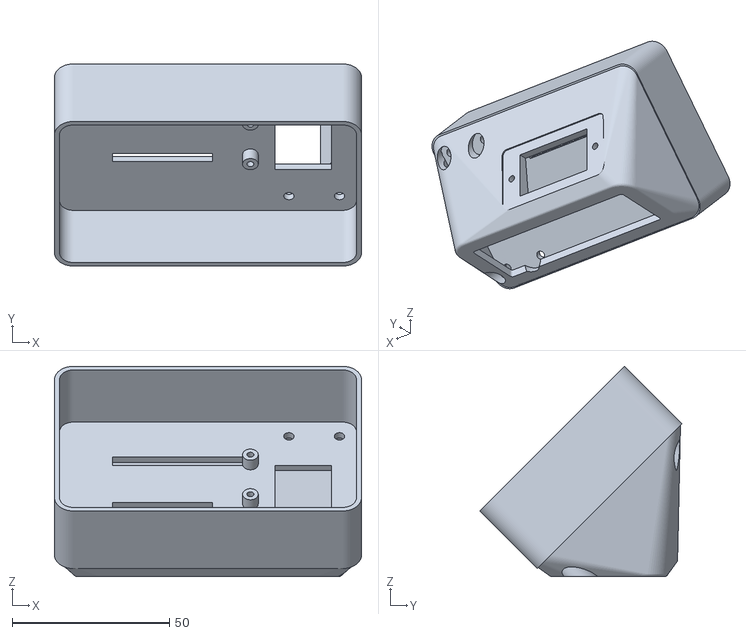
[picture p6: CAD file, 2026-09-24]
enclosure/stl/v2-stand.stl
97.6 x 64.2 x 66.8

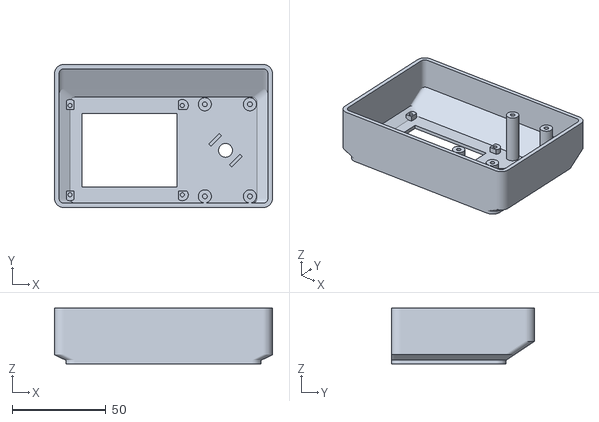
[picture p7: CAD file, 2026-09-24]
enclosure/stl/tapered-front-m25.stl
116.0 x 76.2 x 29.6

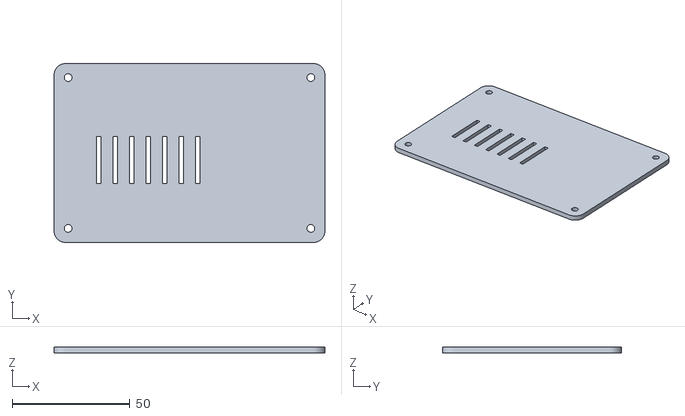
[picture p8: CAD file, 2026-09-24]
enclosure/stl/back.stl
115.0 x 76.0 x 2.40

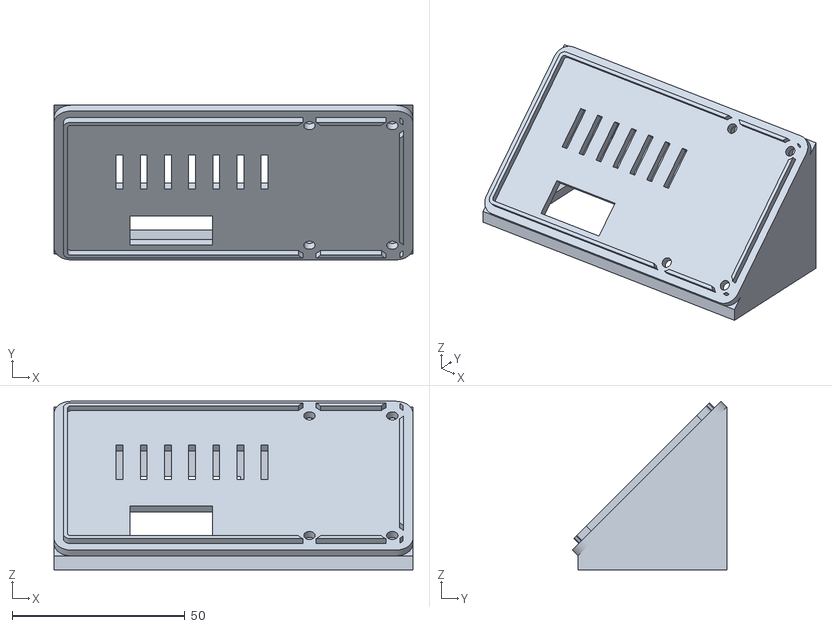
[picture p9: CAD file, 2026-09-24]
enclosure/stl/slim-stand.stl
104.0 x 44.8 x 48.8

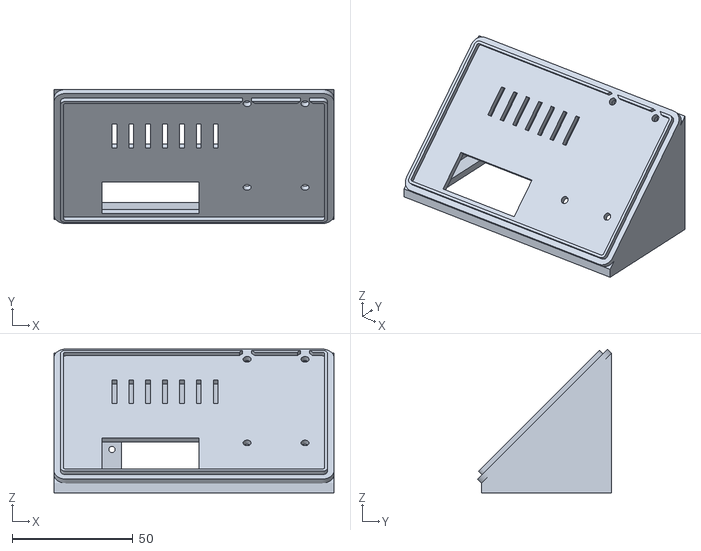
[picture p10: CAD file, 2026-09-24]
enclosure/stl/tapered-stand.stl
116.0 x 55.6 x 59.6

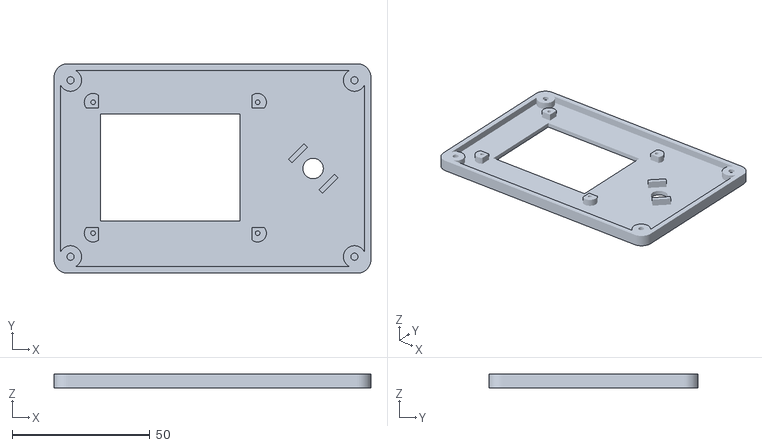
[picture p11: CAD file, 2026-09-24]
enclosure/stl/bezel-fit-mirrored-short.stl
115.0 x 76.0 x 5.00

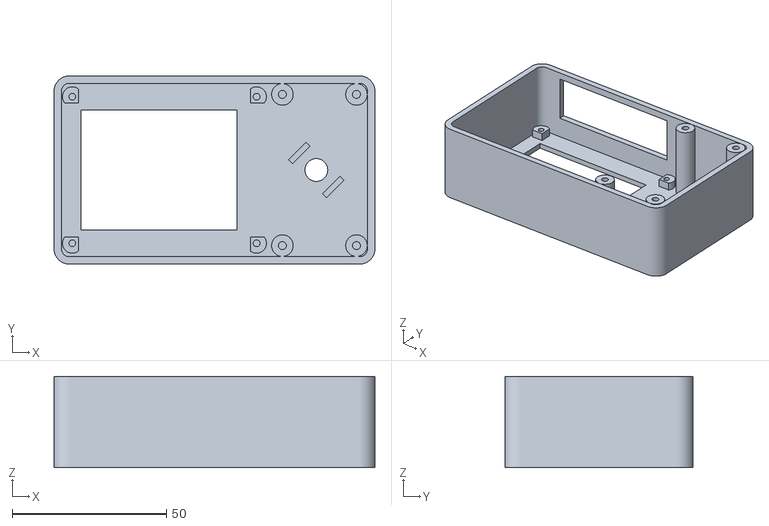
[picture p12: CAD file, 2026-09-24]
enclosure/stl/slim-front-m25.stl
104.0 x 61.0 x 29.6

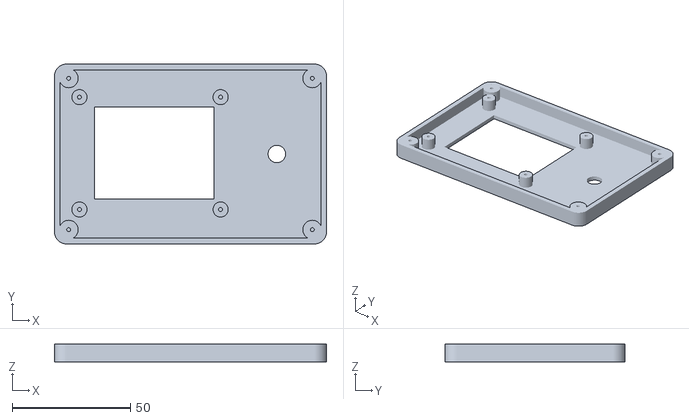
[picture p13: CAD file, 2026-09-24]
enclosure/stl/bezel-fit-m2.stl
115.0 x 76.0 x 7.50

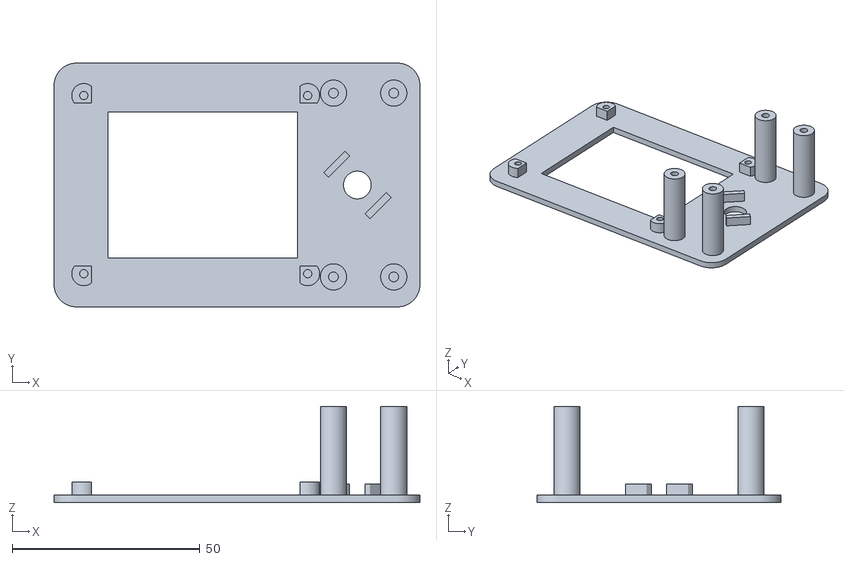
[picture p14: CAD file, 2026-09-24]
enclosure/stl/v2-front-m25.stl
97.6 x 65.0 x 25.6

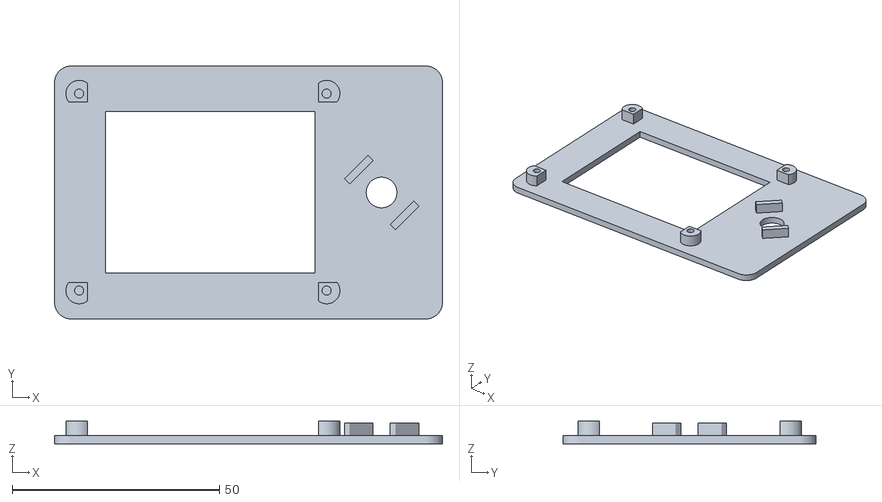
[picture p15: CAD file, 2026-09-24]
enclosure/stl/v2-front-fit-m25.stl
93.6 x 61.0 x 5.47

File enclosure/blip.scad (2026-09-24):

// blip: Brian's Little Information Panel
// Original enclosure, MIT. Units: mm. See README for unverified fit parameters.
// Print front face-down as generated; back flat as generated.
part = "assembly"; // [assembly,front,back,fit,encoder-fit]
$fn = 48;
width = 115;
height = 76;
depth = 32;
wall = 2.4;
face = 2;
corner_radius = 5;
clearance = 0.3;
// Adafruit V2 PCB in landscape: 64.770 x 52.578, holes 59.690 x 47.498.
board_y = 12;
board_w = 64.770;
board_h = 52.578;
hole_inset = 2.540;
post_radius = 3.2;
post_inward = 2.0; // Relieve LCD-facing sides; retain 1.15 mm around M2 pilot.
// Distance from front exterior to screen-facing PCB surface. Verify on assembly.
board_z = 7.5 - 0.1*25.4; // Physical fit correction: 2.54 mm closer to face.
window_w = 50.5;
window_h = 38.9;
window_x = 8 + 34.20; // Opening stays fixed; only the board mounts move.
window_y = board_y + 26.34;
// Mirror the original PCB mounting pattern about the fixed window center.
board_x = 2*window_x - 8 - board_w;
knob_x = 94;
knob_y = 38;
shaft_hole = 7.4;
// PEC11+SWITCH body footprint from Adafruit encoder PCB, rotated 45 degrees.
// Short rails locate the body; shaft nut retains it axially. Verify actual fit.
encoder_body_h = 13.2;
encoder_gap = 0.3; // Per-side clearance.
encoder_angle = 45;
encoder_rail_length = 8;
encoder_rail_wall = 1.8;
encoder_rail_height = 3;
board_screw_pilot = 1.7; // M2 board screws; tune after fit print.
case_screw_pilot = 2.6; // M3 case screws form threads in plastic.
case_screw_clearance = 3.3; // Lid: M3 screws pass freely into shell posts.
back_thickness = 2.4;
// Broad service opening accommodates the Feather USB plug without a panel extension.
// Narrow/relocate after confirming the physical stack and cable boot.
usb_x = board_x + 8;
usb_width = 51;
usb_z = 10;
usb_height = 17;

module outline(w,h,r) {
 hull() for(x=[r,w-r], y=[r,h-r]) translate([x,y]) circle(r=r);
}
module screw_positions() {
 for(x=[6,width-6],y=[6,height-6]) translate([x,y,0]) children();
}
module display_positions() {
 for(x=[hole_inset,board_w-hole_inset],y=[hole_inset,board_h-hole_inset])
  translate([board_x+x,board_y+y,0]) children();
}
module display_posts() {
 for(x=[hole_inset,board_w-hole_inset],y=[hole_inset,board_h-hole_inset])
  translate([board_x+x,board_y+y,0]) intersection() {
   cylinder(h=board_z,d=2*post_radius);
   // Clip both inward-facing sides at each corner, preserving hole centers.
   translate([x<board_w/2 ? -post_radius : -post_inward,
              y<board_h/2 ? -post_radius : -post_inward,0])
    cube([post_radius+post_inward,post_radius+post_inward,board_z]);
  }
}
module encoder_index() {
 translate([knob_x,knob_y,0]) rotate([0,0,encoder_angle])
  for(side=[-1,1])
   translate([-encoder_rail_length/2,
    side>0 ? encoder_body_h/2+encoder_gap : -encoder_body_h/2-encoder_gap-encoder_rail_wall,
    face-0.1])
    cube([encoder_rail_length,encoder_rail_wall,encoder_rail_height+0.1]);
}
module front() {
 difference() {
  union() {
   linear_extrude(face) outline(width,height,corner_radius);
   difference() {
    linear_extrude(depth) outline(width,height,corner_radius);
    translate([wall,wall,face]) linear_extrude(depth)
      outline(width-2*wall,height-2*wall,corner_radius-wall);
   }
   // Display posts attach to the face; screws run in from the PCB side.
   display_posts();
   encoder_index();
   screw_positions() cylinder(h=depth-back_thickness,d=8);
  }
  translate([window_x-window_w/2,window_y-window_h/2,-1])
   cube([window_w,window_h,face+2]);
  translate([knob_x,knob_y,-1]) cylinder(h=face+2,d=shaft_hole);
  // Blind pilot holes leave the exterior face intact; no inserts or nuts.
  display_positions()
   translate([0,0,face]) cylinder(h=board_z+1,d=board_screw_pilot);
  screw_positions()
   translate([0,0,face]) cylinder(h=depth,d=case_screw_pilot);
  translate([usb_x,height-wall-1,usb_z]) cube([usb_width,wall+2,usb_height]);
 }
}
module back() {
 difference() {
  linear_extrude(back_thickness) outline(width,height,corner_radius);
  screw_positions() translate([0,0,-1]) cylinder(h=back_thickness+2,d=case_screw_clearance);
  // Small vent slots; the lid can be removed to reach BOOTSEL/RESET.
  for(x=[18:7:65]) translate([x,25,-1]) cube([2,20,back_thickness+2]);
 }
}
module fit() {
 // Alignment and screw-fit test using the same pilot holes as the full shell.
 intersection() {front();translate([-1,-1,-1]) cube([width+2,height+2,max(board_z,face+encoder_rail_height)+1]);}
}
if(part=="front") front();
else if(part=="back") back();
else if(part=="fit") fit();
else if(part=="encoder-fit") intersection() {
 front();
 translate([knob_x-16,knob_y-16,0]) cube([32,32,face+encoder_rail_height]);
}
else {
 color("#343c48") front();
 color("#687885") translate([0,0,depth+8]) back();
 // Illustrative component envelopes, not printable/vendor models.
 %translate([board_x,board_y,board_z]) cube([board_w,board_h,1.6]);
 %translate([knob_x,knob_y,-12]) cylinder(h=12,d=18);
}

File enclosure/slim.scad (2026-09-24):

// blip: Brian's Little Information Panel
// Original enclosure, MIT. Units: mm. See README for unverified fit parameters.
// Print front face-down as generated; back flat as generated.
part = "desk-preview"; // [desk-preview,assembly,front,stand,usb-plate,back,fit,encoder-fit]
// Compact enclosure with a screw-on hollow 45-degree stand/rear cover.
$fn = 48;
width = 104;
height = 61;
depth = 32;
wall = 2.4;
face = 2;
corner_radius = 5;
clearance = 0.3;
// Adafruit V2 PCB in landscape: 64.770 x 52.578, holes 59.690 x 47.498.

board_w = 64.770;
board_h = 52.578;
board_y = (height-board_h)/2;
board_x = 3.4;
hole_inset = 2.540;
post_radius = 3.2;
post_inward = 2.0; // Relieve LCD-facing sides; retain 0.90 mm around M2.5 pilot.
// Distance from front exterior to screen-facing PCB surface. Verify on assembly.
board_z = 7.5 - 0.1*25.4; // Physical fit correction: 2.54 mm closer to face.
window_w = 50.5;
window_h = 38.9;
window_x = board_x + board_w - 34.20; // Preserve corrected PCB/window offset.
window_y = board_y + 26.34;
knob_x = 85;
knob_y = height/2;
shaft_hole = 7.4;
// PEC11+SWITCH body footprint from Adafruit encoder PCB, rotated 45 degrees.
// Short rails locate the body; shaft nut retains it axially. Verify actual fit.
encoder_body_h = 13.2;
encoder_gap = 0.3; // Per-side clearance.
encoder_angle = 45;
encoder_rail_length = 8;
encoder_rail_wall = 1.8;
encoder_rail_height = 3;
board_screw_pilot = 2.2; // M2.5 board screws; tune after fit print.
case_screw_pilot = 2.6; // M3 case screws form threads in plastic.
case_screw_clearance = 3.3; // Lid: M3 screws pass freely into shell posts.
back_thickness = 2.4;
stand_wall = 3;
stand_base = 3;
stand_inset = 0;
stand_foot = 4;
screw_access = 7.5; // Driver/head access through stand, not through rear cover.
stand_y0 = depth/sqrt(2);
stand_y1 = (depth+height)/sqrt(2);
stand_z1 = height/sqrt(2)+stand_foot;
usb_rear_x = 38;
usb_rear_z = 18;
usb_plate_w = 48;
usb_plate_h = 26;
usb_plate_t = 2.4;
usb_slot_w = 18; // Universal pigtail opening; tailor plate to chosen extension.
usb_slot_h = 10;
usb_screw_spacing = 40;
// Broad service opening accommodates the Feather USB plug without a panel extension.
// Narrow/relocate after confirming the physical stack and cable boot.
usb_x = board_x + 8;
usb_width = 51;
usb_z = 10;
usb_height = 17;

module outline(w,h,r) {
 hull() for(x=[r,w-r], y=[r,h-r]) translate([x,y]) circle(r=r);
}
module screw_positions() {
 // Four posts in the electronics-free strips above/below the encoder.
 for(x=[74,width-6],y=[6,height-6]) translate([x,y,0]) children();
}
module display_positions() {
 for(x=[hole_inset,board_w-hole_inset],y=[hole_inset,board_h-hole_inset])
  translate([board_x+x,board_y+y,0]) children();
}
module display_posts() {
 for(x=[hole_inset,board_w-hole_inset],y=[hole_inset,board_h-hole_inset])
  translate([board_x+x,board_y+y,0]) intersection() {
   cylinder(h=board_z,d=2*post_radius);
   // Clip both inward-facing sides at each corner, preserving hole centers.
   translate([x<board_w/2 ? -post_radius : -post_inward,
              y<board_h/2 ? -post_radius : -post_inward,0])
    cube([post_radius+post_inward,post_radius+post_inward,board_z]);
  }
}
module encoder_index() {
 translate([knob_x,knob_y,0]) rotate([0,0,encoder_angle])
  for(side=[-1,1])
   translate([-encoder_rail_length/2,
    side>0 ? encoder_body_h/2+encoder_gap : -encoder_body_h/2-encoder_gap-encoder_rail_wall,
    face-0.1])
    cube([encoder_rail_length,encoder_rail_wall,encoder_rail_height+0.1]);
}
module front() {
 difference() {
  union() {
   linear_extrude(face) outline(width,height,corner_radius);
   difference() {
    linear_extrude(depth-back_thickness) outline(width,height,corner_radius);
    translate([wall,wall,face]) linear_extrude(depth)
      outline(width-2*wall,height-2*wall,corner_radius-wall);
   }
   // Display posts attach to the face; screws run in from the PCB side.
   display_posts();
   encoder_index();
   screw_positions() cylinder(h=depth-back_thickness,d=7);
  }
  translate([window_x-window_w/2,window_y-window_h/2,-1])
   cube([window_w,window_h,face+2]);
  translate([knob_x,knob_y,-1]) cylinder(h=face+2,d=shaft_hole);
  // Blind pilot holes leave the exterior face intact; no inserts or nuts.
  display_positions()
   translate([0,0,face]) cylinder(h=board_z+1,d=board_screw_pilot);
  screw_positions()
   translate([0,0,face]) cylinder(h=depth,d=case_screw_pilot);
  // Temporary bottom service opening; rear cable routing is still pending.
  translate([usb_x,height-wall-1,usb_z]) cube([usb_width,wall+2,usb_height]);
 }
}
module back() {
 difference() {
  union() {
   linear_extrude(back_thickness) outline(width,height,corner_radius);
   // Locating skirt fits inside shell, clear of the M3 posts.
   difference() {
    translate([wall+clearance,wall+clearance,-2]) linear_extrude(2.1)
     difference() {
      outline(width-2*(wall+clearance),height-2*(wall+clearance),2);
      translate([1.2,1.2]) outline(width-2*(wall+clearance+1.2),height-2*(wall+clearance+1.2),1);
     }
    screw_positions() translate([0,0,-3]) cylinder(h=4,d=7+2*clearance);
   }
  }
  screw_positions() translate([0,0,-3]) cylinder(h=back_thickness+4,d=case_screw_clearance);
  // Cable transfer into the hollow stand, accessible before closing the shell.
  translate([window_x-12,height-18,-3]) cube([24,12,back_thickness+4]);
  for(x=[18:7:60]) translate([x,18,-3]) cube([2,14,back_thickness+4]);
 }
}
module fit() {
 // Alignment and screw-fit test using the same pilot holes as the full shell.
 intersection() {front();translate([-1,-1,-1]) cube([width+2,height+2,max(board_z,face+encoder_rail_height)+1]);}
}
module closed_preview() {
 color("#25303c") front();
 color("#354252") translate([0,0,depth-back_thickness]) back();
 // Visual placeholders only: LCD surface and knob, not vendor models.
 color("#101c25") translate([window_x-window_w/2,window_y-window_h/2,face+0.3])
  cube([window_w,window_h,0.5]);
 color("#46596b") translate([knob_x,knob_y,-12]) cylinder(h=12,d=18);
}
// Assembly pose: readable face points forward/up at 45 degrees.
module desk_pose() {
 translate([0,height/sqrt(2),(height+depth)/sqrt(2)+stand_foot])
  rotate([225,0,0]) children();
}
module wedge() {
 translate([stand_inset,0,0]) rotate([90,0,90])
  linear_extrude(width-2*stand_inset)
   polygon([[stand_y0,0],[stand_y1,0],[stand_y1,stand_z1+0.05],
            [stand_y0,stand_foot+0.05]]);
}
module stand() {
 difference() {
  union() {
   // Rear cover joins the wedge; the M3 screws also fasten the stand.
   desk_pose() translate([0,0,depth-back_thickness]) back();
   difference() {
    wedge();
    // Hollow interior; front lip supports the start of the 45-degree roof.
    translate([stand_inset+stand_wall,stand_y0+stand_wall,stand_base])
     cube([width-2*(stand_inset+stand_wall),
           stand_y1-stand_y0-2*stand_wall,height+depth]);
    // Underside access keeps wiring reachable and avoids a solid wedge print.
    translate([10,stand_y0+7,-1]) cube([width-20,stand_y1-stand_y0-14,stand_base+2]);
   }
  }
  // Removable rear cable plate; bosses stay outside the central opening.
  translate([usb_rear_x-16,stand_y1-stand_wall-1,usb_rear_z-9])
   cube([32,stand_wall+2,18]);
  for(dx=[-usb_screw_spacing/2,usb_screw_spacing/2])
   translate([usb_rear_x+dx,stand_y1+1,usb_rear_z]) rotate([90,0,0])
    cylinder(h=stand_wall+2,d=case_screw_pilot);
  // Coaxial bores reach each rear-cover screw from below/behind the stand.
  // Start beyond the cover so its 3.3 mm clearance holes remain intact.
  desk_pose() screw_positions() translate([0,0,depth+0.1])
   cylinder(h=height*2,d=screw_access);
 }
}
module usb_plate() {
 difference() {
  linear_extrude(usb_plate_t) outline(usb_plate_w,usb_plate_h,2);
  translate([(usb_plate_w-usb_slot_w)/2,(usb_plate_h-usb_slot_h)/2,-1])
   cube([usb_slot_w,usb_slot_h,usb_plate_t+2]);
  for(dx=[-usb_screw_spacing/2,usb_screw_spacing/2])
   translate([usb_plate_w/2+dx,usb_plate_h/2,-1])
    cylinder(h=usb_plate_t+2,d=case_screw_clearance);
  // A small zip tie secures the extension body to the rear plate.
  for(dx=[-usb_slot_w/2-3,usb_slot_w/2+3])
   translate([usb_plate_w/2+dx-1,usb_plate_h/2-2,-1])
    cube([2,4,usb_plate_t+2]);
 }
}
module rear_plate_pose() {
 translate([usb_rear_x-usb_plate_w/2,stand_y1+usb_plate_t,usb_rear_z-usb_plate_h/2])
  rotate([90,0,0]) children();
}
module stand_print() {
 // Base down. The front lip supports the start of the sloped rear cover.
 stand();
}
module desk_preview() {
 desk_pose() {
  color("#25303c") front();
  color("#101c25") translate([window_x-window_w/2,window_y-window_h/2,face+0.3])
   cube([window_w,window_h,0.5]);
  color("#46596b") translate([knob_x,knob_y,-12]) cylinder(h=12,d=18);
 }
 color("#172029") stand();
 color("#354252") rear_plate_pose() usb_plate();
}
if(part=="desk-preview") desk_preview();
else if(part=="front") front();
else if(part=="stand") stand_print();
else if(part=="usb-plate") usb_plate();
else if(part=="back") back();
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

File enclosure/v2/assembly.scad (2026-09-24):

// Blip V2 compact case. All dimensions mm. MIT.
// Shared front preserves the physically tested screen/knob fit.
include <front-geometry.scad>
part="preview"; // [preview,print-layout,assembled,front,stand,usb-plate,back,section,internals,hardware-clearance,case-clearance]
depth=28; // Compact wiring required; full-height jumper housings will not fit.
wall=1.6;
shell_clearance=0.4; // Rear walls sit OUTSIDE the entire successful fit-bezel outline.
seam_gap=0.15;
back_t=2.4;
case_pilot=2.6; // M3 threads form in printed plastic.
case_clearance=3.3;
case_post_r=3.5;
stand_wall=3;
stand_base=3;
stand_foot=4;
stand_taper=4; // Per-side inset at the foot; cover interface stays full width.
stand_rear_inset=3;
stand_corner=8;
stand_roundover=1.2;
stand_y0=depth/sqrt(2);
stand_y1=(depth+height)/sqrt(2);
usb_x=36;
usb_z=18;
usb_plate_w=48; usb_plate_h=26; usb_plate_t=2.4;
usb_slot_w=18; usb_slot_h=10; usb_screw_spacing=40;
// Relocated Feather: components toward LCD, header/pin side toward rear cover.
feather_x=12; feather_y=16; feather_z=21.3; // z is the pin-side PCB surface.
feather_wire_height=3; // General wire space; header rows have deeper dedicated slots.
feather_pin_height=10; // Reserved projection from PCB into base; header length is an estimate.
// Vendor header pad extents transformed into the front's coordinates.
// Each row includes the 2.54 mm header carrier footprint.
feather_header_rows=[[feather_x+5.08,feather_y+1.27,40.64],
                     [feather_x+5.08,feather_y+21.6535,30.48]];
feather_holes_local=[[2.54,2.54],[2.54,20.32]];
module feather_pose() {
 translate([feather_x+50.8,feather_y,feather_z]) rotate([180,0,180]) children();
}
module feather_holes() {
 for(p=feather_holes_local) translate([feather_x+50.8-p[0],feather_y+p[1],0]) children();
}
module feather_mounts() {
 // Posts start at the pin-side PCB surface; holes open toward the LCD.
 feather_holes() translate([0,0,feather_z-depth+back_t])
  difference(){cylinder(h=depth-back_t-feather_z+0.1,r=2.5);translate([0,0,-0.1])cylinder(h=5,d=2.2);}
}
module feather_pcb_proxy() {
 feather_pose() difference() {
  cube([50.8,22.86,1.6]);
  for(p=feather_holes_local) translate([p[0],p[1],-0.1]) cylinder(h=1.8,d=2.5);
 }
}
module feather_components_proxy() {
 // Approximate full-board component envelope, relieved around mounting holes.
 feather_pose() difference() {
  translate([0,0,1.6])cube([50.8,22.86,5.9]);
  for(p=feather_holes_local)translate([p[0],p[1],0])cylinder(h=8,r=2.5);
 }
}
module feather_wiring_proxy() {
 // Actual wires route between these pads; this is a conservative board-wide space.
 difference() {
  translate([feather_x,feather_y,feather_z+0.01])cube([50.8,22.86,feather_wire_height]);
  feather_holes()translate([0,0,feather_z])cylinder(h=feather_wire_height+1,r=2.7);
 }
}
module feather_pins_proxy() {
 for(row=feather_header_rows)
  translate([row[0],row[1]-1.27,feather_z+0.01])cube([row[2],2.54,feather_pin_height]);
}
module feather_pin_reliefs() {
 // These pass through the rear cover into the hollow stand, never out of the case.
 // Preserve the two mount roots where the slot's clearance margin approaches them.
 difference() {
  for(row=feather_header_rows)
   translate([row[0]-0.6,row[1]-1.9,feather_z-0.1])cube([row[2]+1.2,3.8,feather_pin_height+0.2]);
  feather_holes()translate([0,0,feather_z-0.2])cylinder(h=feather_pin_height+0.4,r=2.5);
 }
}
module feather_usb_proxy() {
 // Existing flexible right-angle cable: 0.600 inch projection, estimated cross-section.
 feather_pose() translate([-15.24,5.93,0])cube([15.24,11,5.5]);
}
module feather_qt_proxy() {
 feather_pose()translate([45.8,4.255,1.6])cube([13,8,3.5]);
}
module screen_headers_proxy(extra=0) {
 // Dual-row socket outlines from the vendor footprint, not the old narrow proxies.
 translate([board_x,board_y+board_h,board_z+1.6])rotate([0,0,-90]) {
  translate([5.08,37.719-4.064,0])cube([40.64,8.128,4.5+extra]);
  translate([15.24,37.719+18.796,0])cube([30.48,8.128,4.5+extra]);
 }
}
module electronics_proxy() {
 screen_pcb();lcd();encoder_body();encoder_pcb();screen_headers_proxy(2);
 feather_pcb_proxy();feather_components_proxy();feather_wiring_proxy();feather_pins_proxy();feather_usb_proxy();feather_qt_proxy();
}

module case_positions() {
 for(x=[72.5,width-5],y=[6,height-6]) translate([x,y,0]) children();
}
module outer_outline() {offset(delta=shell_clearance+wall)outline();}
module front() {
 difference() {
  union() {
   fit();
   // Only a flat perimeter flange is added to the proven fit plate.
   linear_extrude(face,convexity=10)
    difference(){outer_outline();offset(delta=-0.1)outline();}
   case_positions() cylinder(h=depth-back_t,r=case_post_r);
  }
  case_positions() translate([0,0,face]) cylinder(h=depth,d=case_pilot);
 }
}
module back() {
 difference() {
  union() {
   linear_extrude(back_t) outer_outline();
   feather_mounts();
   // Walls belong to the rear piece. Their inside boundary clears the complete
   // test bezel footprint; no wall or registering skirt steals its flat area.
   translate([0,0,face+seam_gap-(depth-back_t)])
    linear_extrude(depth-back_t-face-seam_gap+0.1,convexity=10)
     difference(){outer_outline();offset(delta=shell_clearance)outline();}
  }
  case_positions() translate([0,0,-3]) cylinder(h=back_t+4,d=case_clearance);
  // Large wiring/service transfer into the hollow stand.
  translate([68,19,-3]) cube([18,24,back_t+4]);
  translate([0,0,-(depth-back_t)])feather_pin_reliefs();
 }
}
module desk_pose() {
 translate([0,height/sqrt(2),(height+depth)/sqrt(2)+stand_foot]) rotate([225,0,0]) children();
}
module stand_footprint(inset=0) {
 // Rounded footprint tucked under the display, with a broad flat contact ring.
 r=max(1,stand_corner-inset);
 x=stand_taper+inset;
 y=stand_y0+2+inset;
 w=width-2*x;
 d=stand_y1-stand_rear_inset-inset-y;
 hull() for(px=[x+r,x+w-r],py=[y+r,y+d-r])
  translate([px,py])circle(r=r);
}
module stand_roof(inset=0) {
 // Bury the loft inside the cover so its edge cannot form coincident sliver faces.
 // The cover itself supplies the exact outer mating outline.
 desk_pose() translate([0,0,depth-0.5]) linear_extrude(0.1)
  offset(delta=-inset-0.3) outer_outline();
}
module usb_landing() {
 // Retain a flat rear patch so the existing removable plate still seats properly.
 translate([usb_x-usb_plate_w/2,stand_y1,usb_z-usb_plate_h/2]) rotate([90,0,0])
  linear_extrude(0.1) hull()
   for(x=[3,usb_plate_w-3],y=[3,usb_plate_h-3])translate([x,y])circle(r=3);
}
module stand_envelope() {
 hull() {
  stand_roof();
  usb_landing();
  // Quarter-circle samples soften the transition onto the desk without spheres
  // or a costly Minkowski sum. The lowest section remains exactly at Z=0.
  for(a=[0:15:90]) translate([0,0,stand_roundover*(1-cos(a))])
   linear_extrude(0.02) stand_footprint(stand_roundover*(1-sin(a)));
 }
}
module stand_cavity() {
 // Follow the taper instead of punching a rectangular void through the sides.
 hull() {
  stand_roof(stand_wall);
  translate([0,0,stand_base])linear_extrude(0.1)stand_footprint(stand_wall);
 }
}
module stand() {
 difference() {
  union() {
   desk_pose() translate([0,0,depth-back_t]) back();
   difference() {
    stand_envelope();
    stand_cavity();
    translate([0,0,-1])linear_extrude(stand_base+2)stand_footprint(7);
   }
  }
  // The wider shell overhangs the old rear plane. Recess its plate-sized patch
  // back to that plane so the unchanged USB plate still seats flat.
  translate([usb_x-usb_plate_w/2,stand_y1+10,usb_z-usb_plate_h/2])rotate([90,0,0])
   linear_extrude(10)offset(delta=0.25)usb_plate_outline();
  translate([usb_x-16,stand_y1-10,usb_z-9]) cube([32,11,18]);
  for(dx=[-usb_screw_spacing/2,usb_screw_spacing/2]) translate([usb_x+dx,stand_y1+1,usb_z]) rotate([90,0,0]) cylinder(h=11,d=case_pilot);
  desk_pose() case_positions() translate([0,0,depth+0.1]) cylinder(h=height*2,d=7.5);
  desk_pose()feather_pin_reliefs();
 }
}
module usb_plate_outline() {
 hull() for(x=[2,usb_plate_w-2],y=[2,usb_plate_h-2])translate([x,y])circle(r=2);
}
module usb_plate() {
 difference() {
  linear_extrude(usb_plate_t)usb_plate_outline();
  translate([(usb_plate_w-usb_slot_w)/2,(usb_plate_h-usb_slot_h)/2,-1]) cube([usb_slot_w,usb_slot_h,usb_plate_t+2]);
  for(dx=[-usb_screw_spacing/2,usb_screw_spacing/2]) translate([usb_plate_w/2+dx,usb_plate_h/2,-1]) cylinder(h=usb_plate_t+2,d=case_clearance);
  for(dx=[-usb_slot_w/2-3,usb_slot_w/2+3]) translate([usb_plate_w/2+dx-1,usb_plate_h/2-2,-1]) cube([2,4,usb_plate_t+2]);
 }
}
module usb_pose() {
 translate([usb_x-usb_plate_w/2,stand_y1+usb_plate_t,usb_z-usb_plate_h/2]) rotate([90,0,0]) children();
}
module hardware_clearance() {
 // Known board/body envelopes, leaving intended PCB support contact out.
 intersection(){front();electronics_proxy();}
 intersection(){translate([0,0,depth-back_t])back();electronics_proxy();}
 // Check the full-length header allowance against the actual hollow base as well.
 intersection(){stand();desk_pose()feather_pins_proxy();}
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

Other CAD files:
enclosure/stl/bezel-fit-relieved-indexed.stl
enclosure/stl/bezel-fit-m2-m3.stl
enclosure/stl/slim-face-fit-m25.stl
enclosure/stl/bezel-fit-v3.stl
enclosure/stl/v2-usb-plate.stl
enclosure/tapered.scad
enclosure/stl/bezel-fit-v2.stl
enclosure/stl/front.stl
enclosure/stl/tapered-face-fit-m25.stl
enclosure/stl/v2-print-layout.stl
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

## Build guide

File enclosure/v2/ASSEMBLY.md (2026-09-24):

# Compact V2 enclosure

This is the complete **first full-case prototype** around the physically successful
V2 front fit. The screen/window alignment, closer knob, indexing rails and taller
5.468 mm screen posts share the same source geometry as the confirmed fit coupon.
The rear shell, Feather mounting and final cable routing have not yet been printed
and physically verified.

## Physical build feedback — 2026-09-24

The user assembled the preceding printed case and reports that Blip is together
and working. Slightly flexing the plastic let the rotary board fit, but it remains
tight. The subsequent rear-wall and Feather pin-slot revisions in the current
STLs have **not** been printed; the working assembly does not validate those changes.

For the next mechanical revision, the user requests **four Feather mounting posts
instead of two, with slightly more height**. The wiring beneath the Feather is
crowded, and the pins were bent inward; outward routing may help. The required
height increase has not been measured. These mounting changes are still pending:
the current model retains two 4.3 mm posts and the new pin-clearance slots. Any
height change must preserve clearance to the LCD/socket assembly.

## Files and printing

- [`../stl/v2-print-layout.stl`](../stl/v2-print-layout.stl): all three separate parts,
  arranged with their intended print faces on Z=0. Approximate footprint 199 × 96 mm.
- [`../stl/v2-front-m25.stl`](../stl/v2-front-m25.stl): flat front plate and mounting
  posts, face down. The enclosure sidewalls are on the rear piece.
- [`../stl/v2-stand.stl`](../stl/v2-stand.stl): rear shell plus hollow 45-degree stand,
  base down. Includes the sidewalls and relocated Feather's two mounting posts.
- [`../stl/v2-usb-plate.stl`](../stl/v2-usb-plate.stl): removable rear cable plate, flat.
- [`assembly.scad`](assembly.scad): full parametric source. Default is the assembled
  preview. `part="internals"` shows the approximate electronic component layout.
- [`front-geometry.scad`](front-geometry.scad): shared, successful front geometry.

Generate all print STLs with `make enclosure-v2`. The combined STL is a **print
layout**, not a fused assembled object. Split into objects in the slicer if printing
parts separately or assigning support settings. `part="assembled"` is for inspecting
the assembled case; do not print that mode as a single fused object.

Use 0.2 mm layers and 4 wall loops with a nominal 0.4 mm nozzle. No supports should
be needed on the front or USB plate. Inspect the stand's sloping cover, Feather
posts and USB opening in the slicer; use local removable supports if needed, with
access through the open underside. Keep supports out of small screw pilots.

## Size and layout

The outer front/rear footprint is **97.57 × 65 mm**, and the housing thickness
normal to the screen is **28 mm**. V1's widened rear envelope was 116 × 76.24 × 32 mm.
Those dimensions exclude the angled stand and knob. The stand holds the screen at
45 degrees and retains underside access, driver bores and flat base areas for feet.
Its lower footprint tucks inward 4 mm per side relative to the test bezel (6 mm
relative to the expanded rear shell) and 3 mm at the rear relative to the original
stand, with 8 mm
footprint corner radii and a 1.2 mm bottom roundover. The rounded, tapered shell
blends into a flat rear USB-plate landing. The successful front geometry, rear-cover
interface, Feather mounts and USB plate are unchanged by the base-shape revision.
The internal cavity follows the taper, retaining a nominal 3 mm wall allowance.

### Rotary clearance correction

The original full case put 1.6 mm walls inside the successful 93.57 × 61 mm test
bezel footprint. Its nominal 0.4 mm clearance beside the rotary PCB proved too
tight in the real assembly. The replacement moves **all enclosure sidewalls onto
the rear shell and outside the complete test-bezel outline**: 0.4 mm outward
clearance plus 1.6 mm wall thickness. The front gains only a flat 2 mm perimeter
flange; its screen posts, opening, encoder rails and shaft position are unchanged.
The inward registering skirt is removed. The PCB's nominal right-edge clearance
is now 2.4 mm, and the rear wall stops 0.15 mm short of the front flange.

Use the corrected front and rear STLs together; this changes the part split and
outer footprint, so it is not a front-only replacement for the previous rear shell.
The four case screw posts and M3 fasteners retain their positions and lengths.

The Feather is **unplugged from the screen sockets**, rotated so USB points toward
the knob side, and flipped with its **component side toward the LCD and pin side
facing the rear cover**. In the front-face-down coordinate system its pin-side PCB
surface is Z=21.3 mm. Two M2.5 mounts descend from the rear cover to that surface.
The PCB is supported on its pin side; screw heads go on its component side.
Assemble the Feather onto the rear cover before closing the shell.

The **4.3 mm mount height alone does not clear full-length headers or the battery
JST socket**. Two slots now let the header rows project through the rear cover
into the hollow stand. Keep **pins toward the base, components/battery socket
toward the LCD**; the opposite orientation is not the validated arrangement.
The reserved pin projection is **10 mm from the PCB**, an allowance rather than
a measurement of this user's headers. These openings preserve the Feather's
position and the screen clearance instead of lengthening the posts toward the LCD.

The closest modeled Feather components are 2.232 mm behind the screen sockets.
There is a **2 mm low-profile wiring envelope above those sockets**, and a **3 mm
wiring envelope above the Feather's pin-side surface**, supplemented by the two
10 mm header-row allowances through the rear cover. A further 1.3 mm remains
between the general wire envelope and the rear cover. These are clearance budgets,
not measurements of the existing jumper housings.

**The 0.700-inch jumper housings are still outside the wiring allowance.** The
Feather's pins can use the new slots if their projection is at most 10 mm; the
screen connections still require low-profile wiring. Route wires
flat around the board edges and keep joints insulated; do not rely on the lid to
press the wiring down. Removing unused header plastic/sockets
is optional if more routing room is wanted, not a prerequisite assumed by the CAD.

## Hardware and assembly

- Four M2.5 × 4 mm screws for the screen, in 2.2 mm plastic pilot holes.
- Two M2.5 × 4 mm screws for the relocated Feather, also in 2.2 mm pilots.
- Four M3 × 8 mm screws for the case, through 3.3 mm cover holes into 2.6 mm pilots.
- Two M3 × 6 mm screws for the rear USB plate.
- Existing encoder nut/washer, flexible USB extension, a small cable tie, and feet.
- No thread inserts required. No nylon standoff length is assumed.

1. Fit the screen and encoder onto the flat front plate using the already verified
   orientation. Keep the encoder's QT lead routed inward toward the Feather.
2. Prepare and verify the compact eight-wire harness below, with power unplugged.
   Test the electronics before final fastening.
3. Fit the upside-down Feather onto the two rear-cover posts, guiding its header
   rows through the clearance slots. The metal USB socket
   points toward the knob side. Check the actual connector body and solder joints
   against the modeled clearances before tightening.
4. Keep the encoder QT cable on the **Feather**, not the screen. Route its slack
   and the USB extension through the 18 × 24 mm transfer opening into the hollow
   stand, away from case screw posts and the display.
5. Fasten the case through the rear/underside access bores. Secure the extension
   at the rear plate and attach the plate. Add the feet.

The USB plate deliberately reuses V1's generic 18 × 10 mm pass-through and tie slots.
It accommodates the existing extension; it is **not a dimensioned snap-fit mount**
for its female housing. A later true panel connector can use a revised plate alone.
USB plug projection uses the earlier 15.24 mm allowance; its 11 × 5.5 mm cross-section
is still an estimate. Actual cable bend radius and free slack are not proven by CAD.

## Eight-wire connection

Feather to matching FeatherWing header socket: **3.3V, GND, SCK, MOSI (MO), D9,
D10, SDA, SCL**. D9 is TFT chip select; D10 is data/command. The current firmware
writes the display without MISO and polls touch without the IRQ pin. Leave the
unused SD card out. RST can be added to preserve the Wing reset button; EN is
needed only if retaining its power switch behavior.

**Screen power uses the second socket from RST on its 16-position header.** The
third is AREF, although the corresponding Feather RP2040 position is another 3.3V
pin. The initial remote-wiring failure was fixed by moving power to the correct
screen socket. The user then confirmed that the display, touch and encoder worked.
See [Adafruit V2 pinouts](https://learn.adafruit.com/adafruit-2-4-tft-touch-screen-featherwing/pinouts-v2)
and the vendor CAD linked in [README.md](README.md).

## Verification scope

The exports passed `python3 scripts/v2-mesh-check.py`: each individual part is a
connected watertight mesh, and the combined layout contains exactly three parts,
all touching Z=0. Full CGAL renders of `hardware-clearance` and `case-clearance`
were empty (no modeled intersections).

The model checks rigid screen/encoder envelopes, the dual-row socket outlines,
Feather PCB and approximate components, reserved low-profile wire volumes, QT/USB
plug volumes, mounts, screw-head clearance and case-to-case intersections. Intended
mount contact is excluded. Component heights, individual cable routing, wire bend
radii and the final cable termination details are estimates; this is not an electrical
or complete mechanical simulation. The first full enclosure still needs a real fit.

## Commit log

2026-09-21 Build blip USB dashboard with TinyGo firmware and Go companion
    [back.stl, blip.scad, front.stl]
2026-09-24 Publish dashboard updates, compact enclosure, and illustrated build guide
    [assembly.scad, back.stl, bezel-fit-m2-m3.stl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]
